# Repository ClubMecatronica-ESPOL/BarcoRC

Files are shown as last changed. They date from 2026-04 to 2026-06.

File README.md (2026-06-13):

<p align="center">
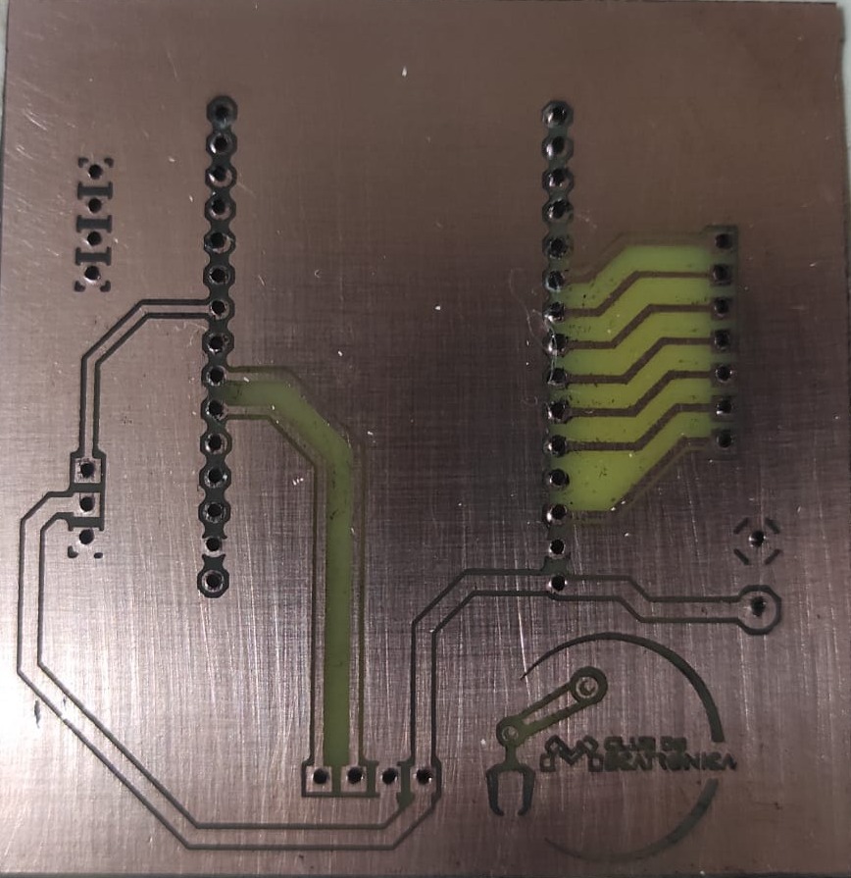
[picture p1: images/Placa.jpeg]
Placa PCB BarcoRC
  
</p>

<h1 align="center">🚤 Proyecto BarcoRC</h1>

<p align="center">
  <strong>Sistema integral de telemetría, potencia y control para embarcación a escala.</strong><br>
  <i>Desarrollado en el marco de las actividades del Club de Mecatrónica - ESPOL.</i>
</p>

---

## 📖 Descripción del Proyecto

**BarcoRC** es un proyecto de ingeniería mecatrónica enfocado en el diseño, construcción y validación de una embarcación a control remoto de alto rendimiento. El sistema resuelve problemas críticos de control inalámbrico y ruido electromagnético mediante el uso de microcontroladores duales, enlaces de radiofrecuencia industriales y placas de circuito impreso (PCB) fabricadas a medida.

### ✨ Características Principales
* **Telemetría de Larga Distancia:** Enlace robusto en modo *Broadcast* utilizando módulos **XBee Pro S1** (IEEE 802.15.4).
* **Control Inteligente:** Interfaz de usuario intuitiva mediante emparejamiento Bluetooth nativo con un control de **PlayStation 4 (DualShock 4)**.
* **Procesamiento Dual:** Arquitectura Maestro/Esclavo impulsada por dos microcontroladores **ESP32**.
* **Potencia y Propulsión:** Motor Brushless gestionado por un ESC (Electronic Speed Controller) con rutinas de filtrado matemático (EMA) para evitar picos de corriente.
* **Hardware Customizado:** PCB manufacturada mediante ablación láser y ataque químico, con planos de masa para mitigar interferencias electromagnéticas (EMI).

---

## 📂 Estructura del Repositorio

El proyecto está organizado de la siguiente manera para facilitar su lectura y escalabilidad:

* 📁 **`/docs`**: Documentación técnica detallada.
  * `hardware.md`: Detalles de la electrónica, PCB y esquema de alimentación.
  * `software.md`: Lógica de control, trama de datos XBee y algoritmos del ESP32.
* 📁 **`/src`**: Código fuente principal (Firmware Arduino).
  * `MAESTRO_BRUSHLESS.ino`: Código del mando transmisor (PS4 a XBee).
  * `ESCLAVO_BRUSHLESS.ino`: Código del barco receptor (XBee a PWM/Motores).
* 📁 **`/hardware`**: Archivos de diseño electrónico.
  * `/proteus`: Esquemáticos y simulaciones del circuito.
* 📁 **`/images`**: Registro fotográfico de la placa, pruebas y ensamblaje.

---

## ⚙️ Requisitos y Dependencias (Software)

Para compilar y cargar el código en los microcontroladores ESP32, es necesario instalar las siguientes librerías en el Arduino IDE:

1. **[Bluepad32](https://github.com/ricardoquesada/bluepad32):** Para la conexión Bluetooth con el mando de PS4 (Solo Maestro).
2. **[ESP32Servo](https://github.com/madhephaestus/ESP32Servo):** Para la generación de señales PWM precisas usando los Timers de hardware del ESP32 (Solo Esclavo).

---

## 🚀 Guía de Inicio Rápido

1. **Clonar el repositorio:**
   ```bash
   git clone [https://github.com/ClubMecatronica-ESPOL/BarcoRC.git](https://github.com/ClubMecatronica-ESPOL/BarcoRC.git)

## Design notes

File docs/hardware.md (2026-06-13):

# 🛠️ Documentación de Hardware: Electrónica y Diseño de PCB

Este documento detalla la arquitectura de hardware de la embarcación, los componentes principales y el diseño de la placa de circuito impreso (PCB) desarrollada para integrar el sistema de control.

---

## 1. Componentes Principales

La electrónica de la embarcación está segmentada en dos módulos principales: el transmisor (mando de control) y el receptor (barco).

### Transmisor (Maestro)
* **Microcontrolador:** ESP32 (Maneja la recepción Bluetooth del control de PS4 y el empaquetado de datos).
* **Módulo de Comunicación:** XBee Pro S1. Actúa como enlace de radiofrecuencia (RF) punto a punto de largo alcance.

### Receptor (Esclavo - Barco)
* **Microcontrolador:** ESP32 (Interpreta la trama de datos y genera las señales PWM).
* **Módulo de Comunicación:** XBee Pro S1.
* **Propulsión Principal:** Motor Brushless acoplado a un ESC (Electronic Speed Controller).
* **Dirección:** Servomotor estándar conectado al timón.
---

## 2. Configuración de Red XBee (Modo Broadcast)

Para minimizar el retardo (delay) en el envío de comandos críticos de dirección y aceleración, los módulos **XBee Pro S1** no utilizan direccionamiento cerrado ni topologías de malla pesadas. En su lugar, se configuraron en **Modo Broadcast (Difusión)**, lo que elimina el tiempo de procesamiento que le toma al módulo buscar y verificar una ruta específica en el aire.

### Parámetros en XCTU:
* **DL (Destination Address Low):** `0xFFFF` (Dirección de Broadcast estándar para que cualquier módulo en el canal escuche la trama).
* **DH (Destination Address High):** `0x0000`
* **MY (Source Address):** Se asigna un identificador único para cada nodo en la red.
* **BD (Baud Rate):** `7` (`115200` bps), configurado para igualar la velocidad de los puertos UART de los microcontroladores.
---

## 3. Gestión de Energía e Interfaz de Potencia

La alimentación del sistema en el barco está centralizada para optimizar el peso y simplificar las conexiones:

* **Alimentación Principal:** Batería LiPo de alta descarga conectada directamente al controlador de velocidad (ESC).
* **Alimentación Lógica (BEC):** Se está utilizando el circuito regulador interno (BEC - Battery Eliminator Circuit) de 5V del propio ESC. Este voltaje de 5V se inyecta directamente al pin **VIN** del ESP32, alimentando así la etapa lógica.
* *(Nota de Desarrollo: Actualmente el sistema opera con conexiones directas sin una etapa de filtrado adicional con capacitores. A medida que avancen las pruebas de carga mecánica en el agua, se evaluará si el ruido del motor Brushless requiere implementar un banco de condensadores de desacople).*

---

## 4. Placa de Circuito Impreso (PCB) a Medida

Para pasar del protoboard a una solución más sólida y evitar desconexiones por las vibraciones mecánicas propias de una embarcación, se manufacturó una PCB personalizada en cobre.

**Método de Fabricación:**
La placa fue fabricada mediante un método híbrido de sustracción que combina fabricación digital y ataque químico:
1. **Ablación Láser:** Se aplicó una capa protectora sobre la placa de cobre virgen y se utilizó un láser de corte/grabado para retirar selectivamente esta máscara, dejando expuestas únicamente las áreas correspondientes al aislamiento de las pistas.
2. **Ataque Químico:** Posteriormente, la placa fue sumergida en Cloruro Férrico, el cual reaccionó y disolvió el cobre expuesto, dejando las pistas limpias y perfectamente definidas bajo la pintura restante.

**Características del Diseño:**
* **Planos de Masa (Ground Planes):** Diseñados para maximizar la unificación de tierras de los diferentes componentes y disipar mejor el calor.
* **Conectores Modulares:** Se integraron pines y regletas para montar y desmontar fácilmente el ESP32 y el módulo XBee sin necesidad de soldarlos directamente a la placa, facilitando recambios.
Aquí podemos ver el resultado del ataque químico sobre el cobre:

Placa de control
---

## 5. Esquemas y Simulación

Toda la validación de conexiones, lógica de pines y disposición de componentes se diseñó previamente.
[Descargar esquema de Proteus del Barco](/hardware/proteus)

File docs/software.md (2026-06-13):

# 💻 Documentación de Software: Lógica y Control (Versión Brushless)

El sistema operativo del barco a control remoto está dividido en una arquitectura de **Maestro (Transmisor)** y **Esclavo (Receptor)**, ejecutados en microcontroladores ESP32 y programados bajo el entorno de Arduino IDE.

Este documento detalla la estructura y el flujo de los scripts `MAESTRO_BRUSHLESS.ino` y `ESCLAVO_BRUSHLESS.ino`.

---

## 1. Arquitectura de Comunicación y Topología Dual

El sistema operativo del barco requiere una configuración asimétrica dividida en dos firmwares independientes cargados en dos microcontroladores ESP32 separados:

1.  **Nodo Maestro (Transmisor):** Dedicado exclusivamente a procesar las interrupciones del stack Bluetooth del control de PS4, mapear las zonas muertas y transmitir los comandos por hardware serial.
2.  **Nodo Esclavo (Receptor):** Dedicado a la escucha continua del puerto serial, filtrado matemático de datos, ejecución de la secuencia de armado y generación de señales PWM de potencia.

### Capa de Enlace en Modo Broadcast (Difusión)
[cite_start]La comunicación por el puerto `Serial2` (pines 16 y 17) opera de manera unidireccional a una tasa de transferencia alta de 115200 baudios[cite: 3, 16, 30, 51]. Al utilizar el método de **Broadcast**, el Maestro inyecta la trama directamente al espectro sin esperar confirmaciones de recepción (ACK) ni establecer handshakes previos. 

Esto garantiza que el retardo entre el movimiento del joystick en tierra y la respuesta del timón o motor en el agua sea prácticamente nulo, optimizando la maniobrabilidad de la embarcación bajo condiciones de estrés operativo.

---

## 2. Arquitectura de Comunicación (Capa de Enlace)

Para garantizar que el barco no interprete ruido electromagnético o paquetes a medias como comandos, se diseñó un protocolo de envío rígido utilizando los módulos XBee por el puerto Serial2 a 115200 baudios.

### Trama de Datos de 4 Bytes
Cada instrucción enviada por el Maestro consta de 4 bytes estrictos:

1.  **Cabecera (Header): `0xFF` (255):** Indica el inicio absoluto de una instrucción.
2.  **Ángulo de Dirección:** Valor entre `0` y `180` grados (Eje X del joystick).
3.  **Aceleración (Potencia):** Valor mapeado entre `0` y `253`. (El límite es 253 para asegurar que un dato nunca coincida accidentalmente con la cabecera `0xFF`).
4.  **Checksum (Validación):** Una suma matemática básica enmascarada `(angulo + velocidad) & 0xFE`.

> **Filtro de Descarte:** Si el Esclavo recibe un Checksum que no coincide matemáticamente con los datos de ángulo y aceleración, ignora el paquete completo, asumiéndolo como corrupto por ruido RF.

---

## 3. Controlador Maestro (Transmisor)

El script `MAESTRO_BRUSHLESS.ino` actúa como el puente entre el usuario (mediante el control de PS4) y el módulo transmisor XBee.

### Flujo de Trabajo y Buenas Prácticas:
* **Integración Bluetooth:** Utiliza la librería `Bluepad32` para emparejar y recibir datos en tiempo real de un control de PlayStation 4.
* **Zonas Muertas (Deadzones):** Se aplica un filtro mecánico en la lectura del joystick (dirección) y de los gatillos (aceleración). Si los valores brutos son menores a `40` o `20` respectivamente, se fuerzan a `0`. Esto evita que el barco se mueva solo por el desgaste físico normal de los resortes del control (drift).
* **Ahorro de Ancho de Banda (Keep-Alive):** El ESP32 solo transmite por RF si detecta un cambio en la posición de los mandos. Sin embargo, para que el receptor sepa que sigue conectado, envía un paquete de "latido" (Keep-Alive) cada 150 milisegundos si no hay actividad.

---

## 4. Controlador Esclavo (Receptor)

El script `ESCLAVO_BRUSHLESS.ino` es el cerebro del barco. Su objetivo principal es interpretar de forma segura las instrucciones del XBee, transformándolas en señales PWM y cuidando los componentes electrónicos.

### Subsistemas Clave:

* **Secuencia de Armado ESC (Electronic Speed Controller):** Al iniciar, el programa envía de forma sostenida un pulso de `1000 microsegundos` durante 3 segundos al ESC. Esto es un requisito de seguridad estándar para que el controlador Brushless inicialice sin disparar el motor.
* **Asignación de Timers (Anti-Vibración):** El ESP32 sufre de colisión de temporizadores de hardware cuando se usan PWMs de forma nativa junto con la librería Servo. Se resuelve forzando el Timer 0 para el Servo (Timón) y el Timer 1 para el ESC (Motor Principal).
* **Filtro EMA (Exponential Moving Average):** Las lecturas válidas de velocidad y dirección no se aplican directamente a los motores. Pasan por una fórmula de suavizado matemático: `Valor = (0.7 * Nuevo_Dato) + (0.3 * Valor_Anterior)`. Esto previene picos de corriente catastróficos que podrían quemar el ESC o reiniciar el ESP32 si el usuario mueve el mando bruscamente de 0 a 100%.
* **Watchdog (Fail-Safe Tolerante):** Si el ESP32 receptor no detecta un paquete válido del maestro en un lapso de **400 ms** (asumiendo pérdida de señal, interferencia severa o control remoto apagado), el barco entra en modo seguro: el timón se bloquea en 90° (centro) y el motor Brushless se apaga de inmediato bajando a 1000 microsegundos.
* **Guillotinas Matemáticas:** Como filtro extra final, se fuerza al servo del timón al centro exacto (90°) si los valores oscilan cerca del punto neutro (85° a 95°), garantizando trayectorias completamente rectas sin oscilaciones del servo.

---

## 5. Dependencias Requeridas
* **Bluepad32:** Para la gestión del control Bluetooth de PS4 (Lado Maestro).
* **ESP32Servo:** Para la correcta manipulación de señales de control en microsegundos y evitar problemas de hardware con los temporizadores nativos (Lado Esclavo).

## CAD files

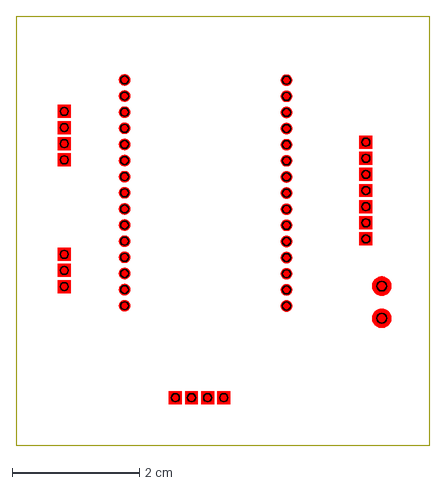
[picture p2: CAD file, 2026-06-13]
hardware/proteus/Barco.DXF
6.51 x 6.76 cm

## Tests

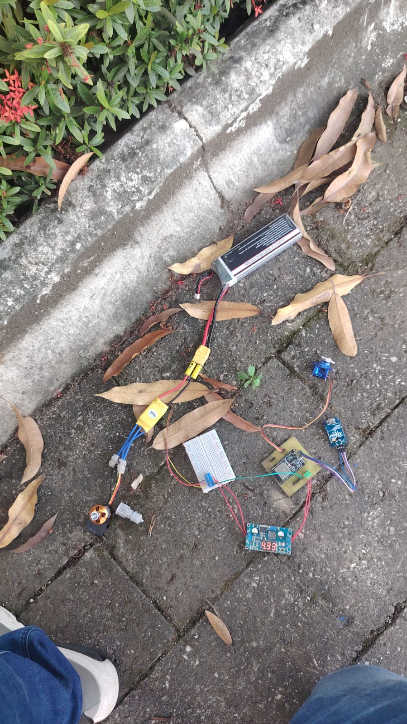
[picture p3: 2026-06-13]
images/prueba_circuito_implementado.jpeg

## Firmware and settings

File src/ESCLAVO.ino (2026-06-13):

#include <Arduino.h>
#include <ESP32Servo.h>

Servo miServo;
// Definición de pines
const int pinServo = 18;
const int pinENA = 14; 
const int pinIN1 = 26; 
const int pinIN2 = 27;

const uint8_t HEADER = 0xFF;

// --- VARIABLES PARA FILTRO DE SUAVIZADO (EMA) ---
float anguloActual = 90.0;     // Centro inicial del servo
float velocidadActual = 126.0; // Centro neutral del motor (entre 0 y 253)
const float alpha = 0.7;       // Factor de respuesta: 0.1 (suave/lento) a 1.0 (instantáneo/brusco)

// Variable para el temporizador de seguridad (Watchdog)
unsigned long ultimaVezRecibido = 0; 

void setup() {

    Serial.begin(115200);
    Serial2.begin(115200, SERIAL_8N1, 16, 17);
    
    // PREVENCIÓN DE COLISIÓN DE TIMERS (Evita vibración en el servo al usar PWM del motor)
    ESP32PWM::allocateTimer(0);
    ESP32PWM::allocateTimer(1);
    ESP32PWM::allocateTimer(2);
    ESP32PWM::allocateTimer(3);
    
    miServo.setPeriodHertz(50); // Frecuencia estándar para servos
    miServo.attach(pinServo, 500, 2350); // Rango de pulso estándar
    
    pinMode(pinIN1, OUTPUT);
    pinMode(pinIN2, OUTPUT);
    
    // Configuración del PWM para el motor (5000Hz es óptimo para el L298N)
    ledcAttach(pinENA, 5000, 8); 
}

void loop() {
    // --- 1. LECTURA Y VALIDACIÓN ---
    while (Serial2.available() >= 4) {
        if (Serial2.read() == HEADER) {
            uint8_t angRecibido = Serial2.read();
            uint8_t velRecibida = Serial2.read();
            uint8_t chkRecibido = Serial2.read();

            uint8_t chkCalculado = (angRecibido + velRecibida) & 0xFE;

            // Si el paquete está corrupto por ruido, se ignora por completo
            if (chkRecibido == chkCalculado) {
                // Filtro Pasa Bajas (suaviza los picos bruscos de corriente)
                anguloActual = (alpha * angRecibido) + ((1.0 - alpha) * anguloActual);
                velocidadActual = (alpha * velRecibida) + ((1.0 - alpha) * velocidadActual);
                
                // Reiniciamos el cronómetro de seguridad porque recibimos un dato válido
                ultimaVezRecibido = millis(); 
            }
        }
    }

    // --- 2. FAIL-SAFE (SEGURIDAD ANTE PÉRDIDA DE SEÑAL) ---
    // Si pasan más de 250ms sin señal del maestro, el sistema entra en modo seguro
    if (millis() - ultimaVezRecibido > 250) {
        anguloActual = 90.0;     // Timón al centro
        velocidadActual = 126.0; // Motores apagados
    }

    // --- 3. EJECUCIÓN FÍSICA ---
    int anguloFinal = round(anguloActual);
    int velFinal = round(velocidadActual);

    // CONTROL DEL SERVO (Con zona muerta de centro absoluto)
    if (anguloFinal > 87 && anguloFinal < 93) {
        miServo.write(90);
    } else {
        miServo.write(anguloFinal);
    }

    // CONTROL DEL MOTOR DC (Con zona muerta amplia de apagado)
    if (velFinal > 137) { // AVANCE
        // Mapeamos el PWM desde 80 (para vencer la inercia del motor) hasta 255
        int pwm = map(velFinal, 137, 253, 80, 255); 
        digitalWrite(pinIN1, HIGH);
        digitalWrite(pinIN2, LOW);
        ledcWrite(pinENA, pwm);
    } 
    else if (velFinal < 117) { // REVERSA
        // Mapeamos el PWM en reversa
        int pwm = map(velFinal, 117, 0, 80, 255);
        digitalWrite(pinIN1, LOW);
        digitalWrite(pinIN2, HIGH);
        ledcWrite(pinENA, pwm);
    } 
    else { // STOP ABSOLUTO
        digitalWrite(pinIN1, LOW);
        digitalWrite(pinIN2, LOW);
        ledcWrite(pinENA, 0); // Cortar voltaje al motor
    }
    
    // Pequeña pausa para permitir que los procesos en segundo plano del ESP32 respiren
    delay(2); 
}

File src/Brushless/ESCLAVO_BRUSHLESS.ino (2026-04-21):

#include <Arduino.h>
#include <ESP32Servo.h>

Servo miServo; 
Servo miESC;   

const int pinServo = 18;
const int pinESC = 13;   

const uint8_t HEADER = 0xFF;

float anguloActual = 90.0;     
float velocidadActual = 126.0; 
const float alpha = 0.7;       

unsigned long ultimaVezRecibido = 0; 

void setup() {
    Serial.begin(115200);
    Serial2.begin(115200, SERIAL_8N1, 16, 17);
    
    // Asignación estricta de Timers para evitar desconexiones
    ESP32PWM::allocateTimer(0);
    ESP32PWM::allocateTimer(1);
    
    // Forzamos a que el servo use el Timer 0 y el ESC el Timer 1
    miServo.setPeriodHertz(50);
    miServo.attach(pinServo, 500, 2400);
    
    miESC.setPeriodHertz(50);
    miESC.attach(pinESC, 1000, 2000); 

    // --- SECUENCIA DE ARMADO (UNIDIRECCIONAL) ---
    Serial.println("Armando ESC (1000us)...");
    miESC.writeMicroseconds(1000); // 1000 = Freno/Apagado
    delay(3000);                   
    Serial.println("¡ESC Listo!");
}

void loop() {
    // --- 1. RECEPCIÓN SEGURA ---
    while (Serial2.available() >= 4) {
        if (Serial2.read() == HEADER) {
            uint8_t angRecibido = Serial2.read();
            uint8_t velRecibida = Serial2.read();
            uint8_t chkRecibido = Serial2.read();

            if (chkRecibido == ((angRecibido + velRecibida) & 0xFE)) {
                anguloActual = (alpha * angRecibido) + ((1.0 - alpha) * anguloActual);
                velocidadActual = (alpha * velRecibida) + ((1.0 - alpha) * velocidadActual);
                ultimaVezRecibido = millis(); 
            }
        }
    }

    // --- 2. FAIL-SAFE TOLERANTE ---
    // Aumentado a 400ms para evitar parpadeos si el XBee pierde un paquete
    if (millis() - ultimaVezRecibido > 400) {
        anguloActual = 90.0;     
        velocidadActual = 126.0; 
    }

    int anguloFinal = round(anguloActual);
    int velFinal = round(velocidadActual);

    // --- 3. GUILLOTINAS MATEMÁTICAS (Eliminador de Fantasmas) ---
    
    // A. Filtro estricto para el Servo (Rango muerto entre 85° y 95°)
    if (anguloFinal > 85 && anguloFinal < 95) {
        miServo.write(90); // Forzar el centro exacto
    } else {
        miServo.write(anguloFinal);
    }

    // B. Lógica Unidireccional para el ESC
    int microsegundosESC = 1000; // Por defecto: Apagado

    // El centro del gatillo es 126. Requerimos al menos 140 para que se digne a arrancar
    if (velFinal > 140) { 
        // Acelerar (R2): Mapeamos hacia adelante
        microsegundosESC = map(velFinal, 140, 253, 1050, 2000); 
    } 
    else {
        // Freno (L2) o Gatillos sueltos (<140): Apagado estricto
        microsegundosESC = 1000;
    }

    miESC.writeMicroseconds(microsegundosESC);

    delay(5); 
}

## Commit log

2026-06-13 Add software documentation for Brushless control system
    This document outlines the architecture and flow of the remote-controlled boat's software, detailing the Master and Slave scripts, communication protocols, and key subsystems.
2026-06-13 Revise hardware documentation for clarity and accuracy
    Updated hardware documentation to clarify the power management and PCB design details.
2026-06-13 Update hardware documentation with new image and link
    Added image of circuit board and updated Proteus scheme link.
